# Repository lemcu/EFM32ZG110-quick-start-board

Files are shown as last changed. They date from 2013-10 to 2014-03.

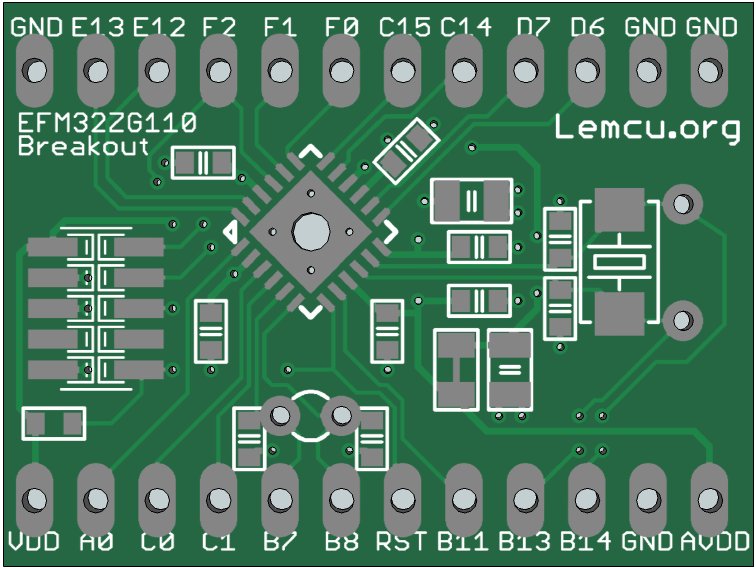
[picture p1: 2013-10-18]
ZeroGecko110BreakoutV1_Top.jpg

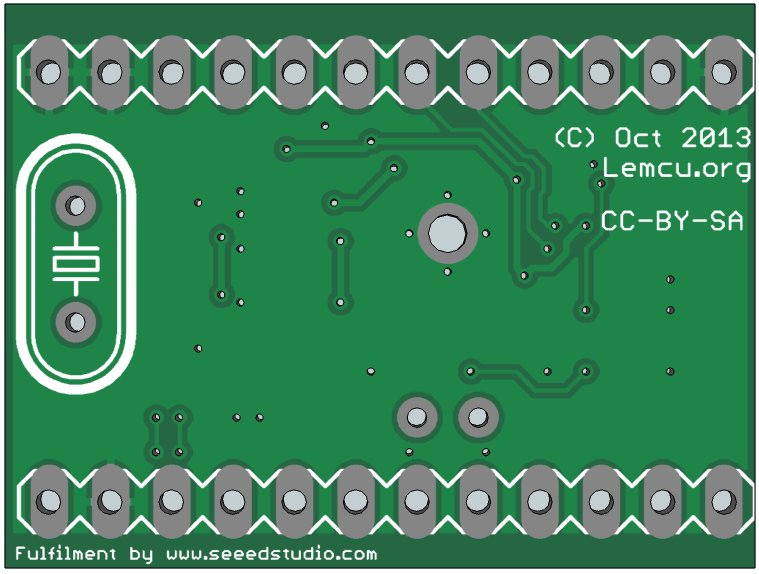
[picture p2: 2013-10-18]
ZeroGecko110BreakoutV1_Bot.jpg

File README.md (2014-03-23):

EFM32ZG110-quick-start-board
============================
This board is designed to be used with [LemcUSB](https://github.com/lemcu/LemcUSB), a purely software based USB peripheral for ARM Cortex M0+ devices.



Zero Gecko 110 quick start breakout board features:

1. USB support using [LemcUSB](https://github.com/lemcu/LemcUSB)
2. 31mm X 23.3mm sized board.
3. Can use either through-hole or SMD High Frequency crystal.
4. Footprint to mount an optional inductor between AVDD and VDD for Analog intensive application.
5. On board SWD Connector.
6. Onboard low noise 3.3V LDO.
7. ESD protection diodes on USB D+ D- lines.

EFM32ZG110 is chosen for presence of onchip ADC instead of EFM32ZG108.




<br />This work is licensed under a <a rel="license" href="http://creativecommons.org/licenses/by-sa/3.0/deed.en_US">Creative Commons Attribution-ShareAlike 3.0 Unported License</a>.

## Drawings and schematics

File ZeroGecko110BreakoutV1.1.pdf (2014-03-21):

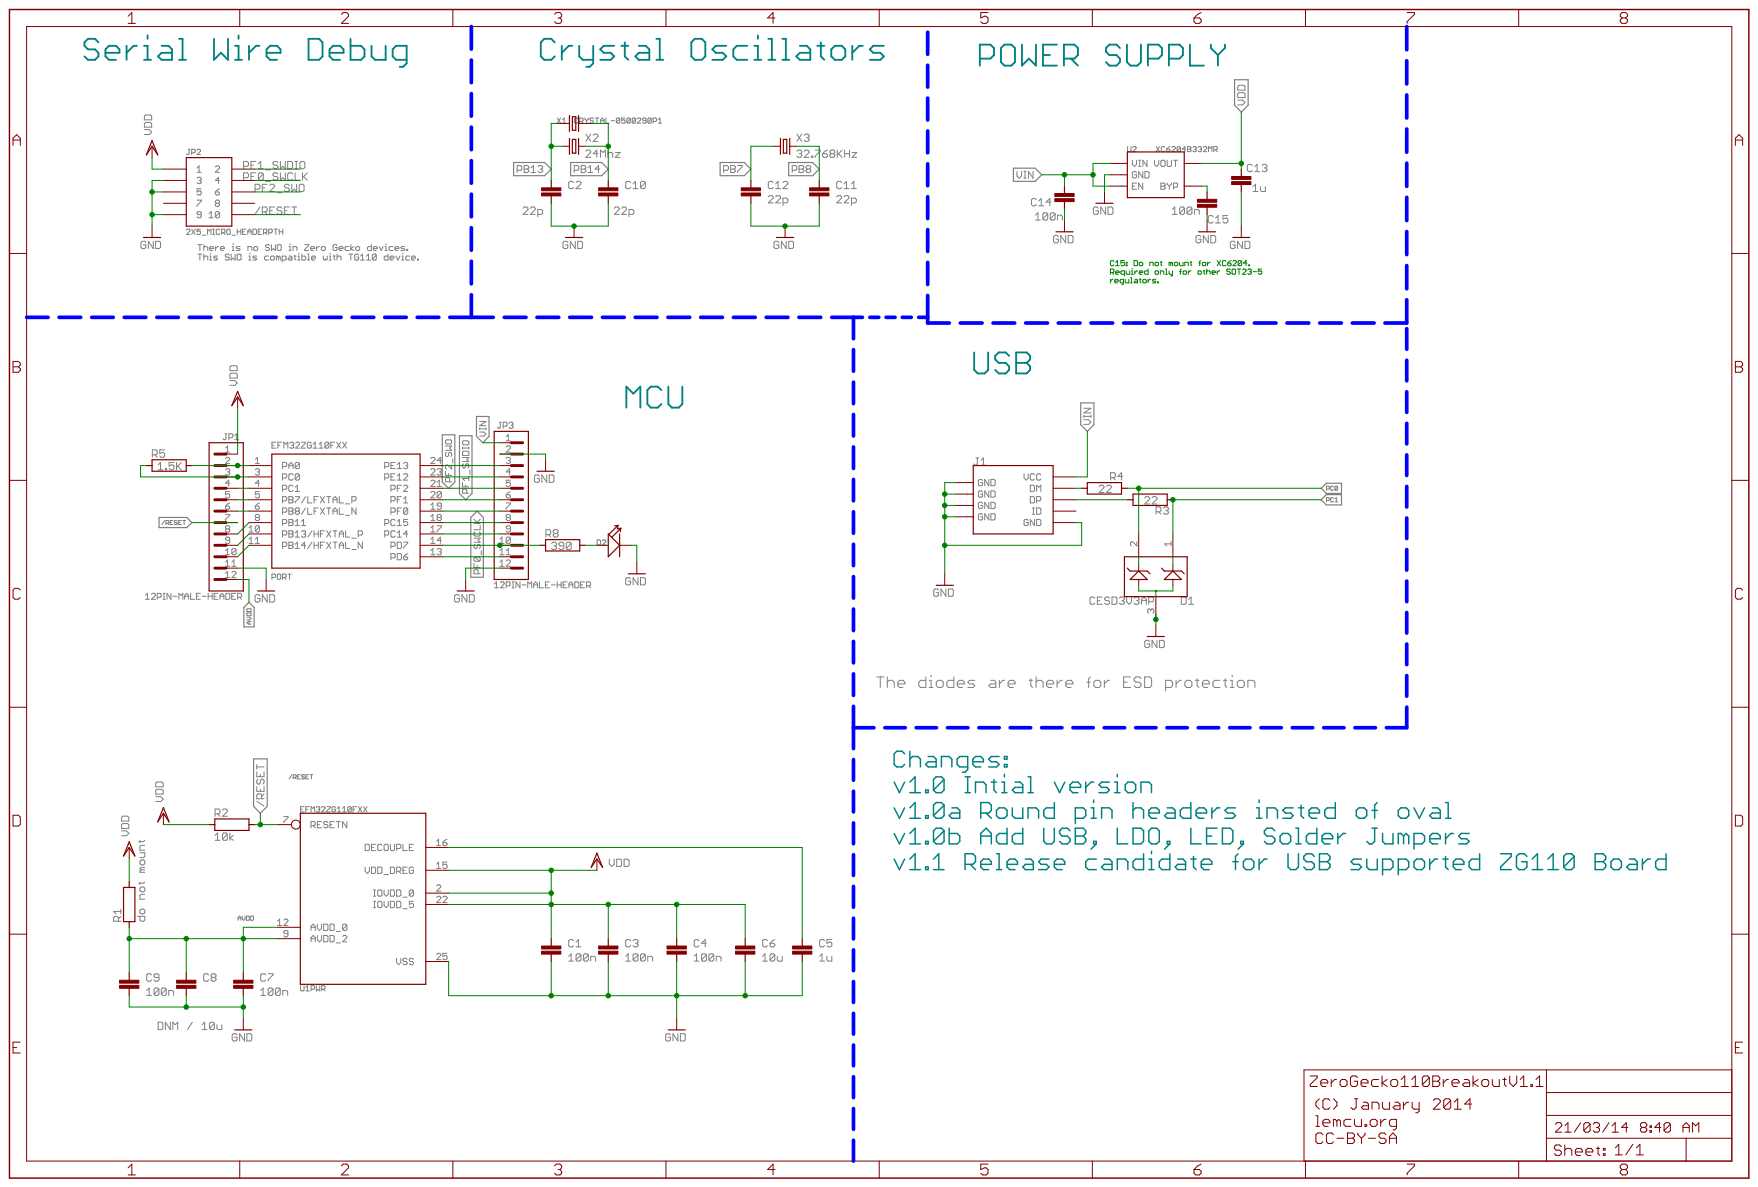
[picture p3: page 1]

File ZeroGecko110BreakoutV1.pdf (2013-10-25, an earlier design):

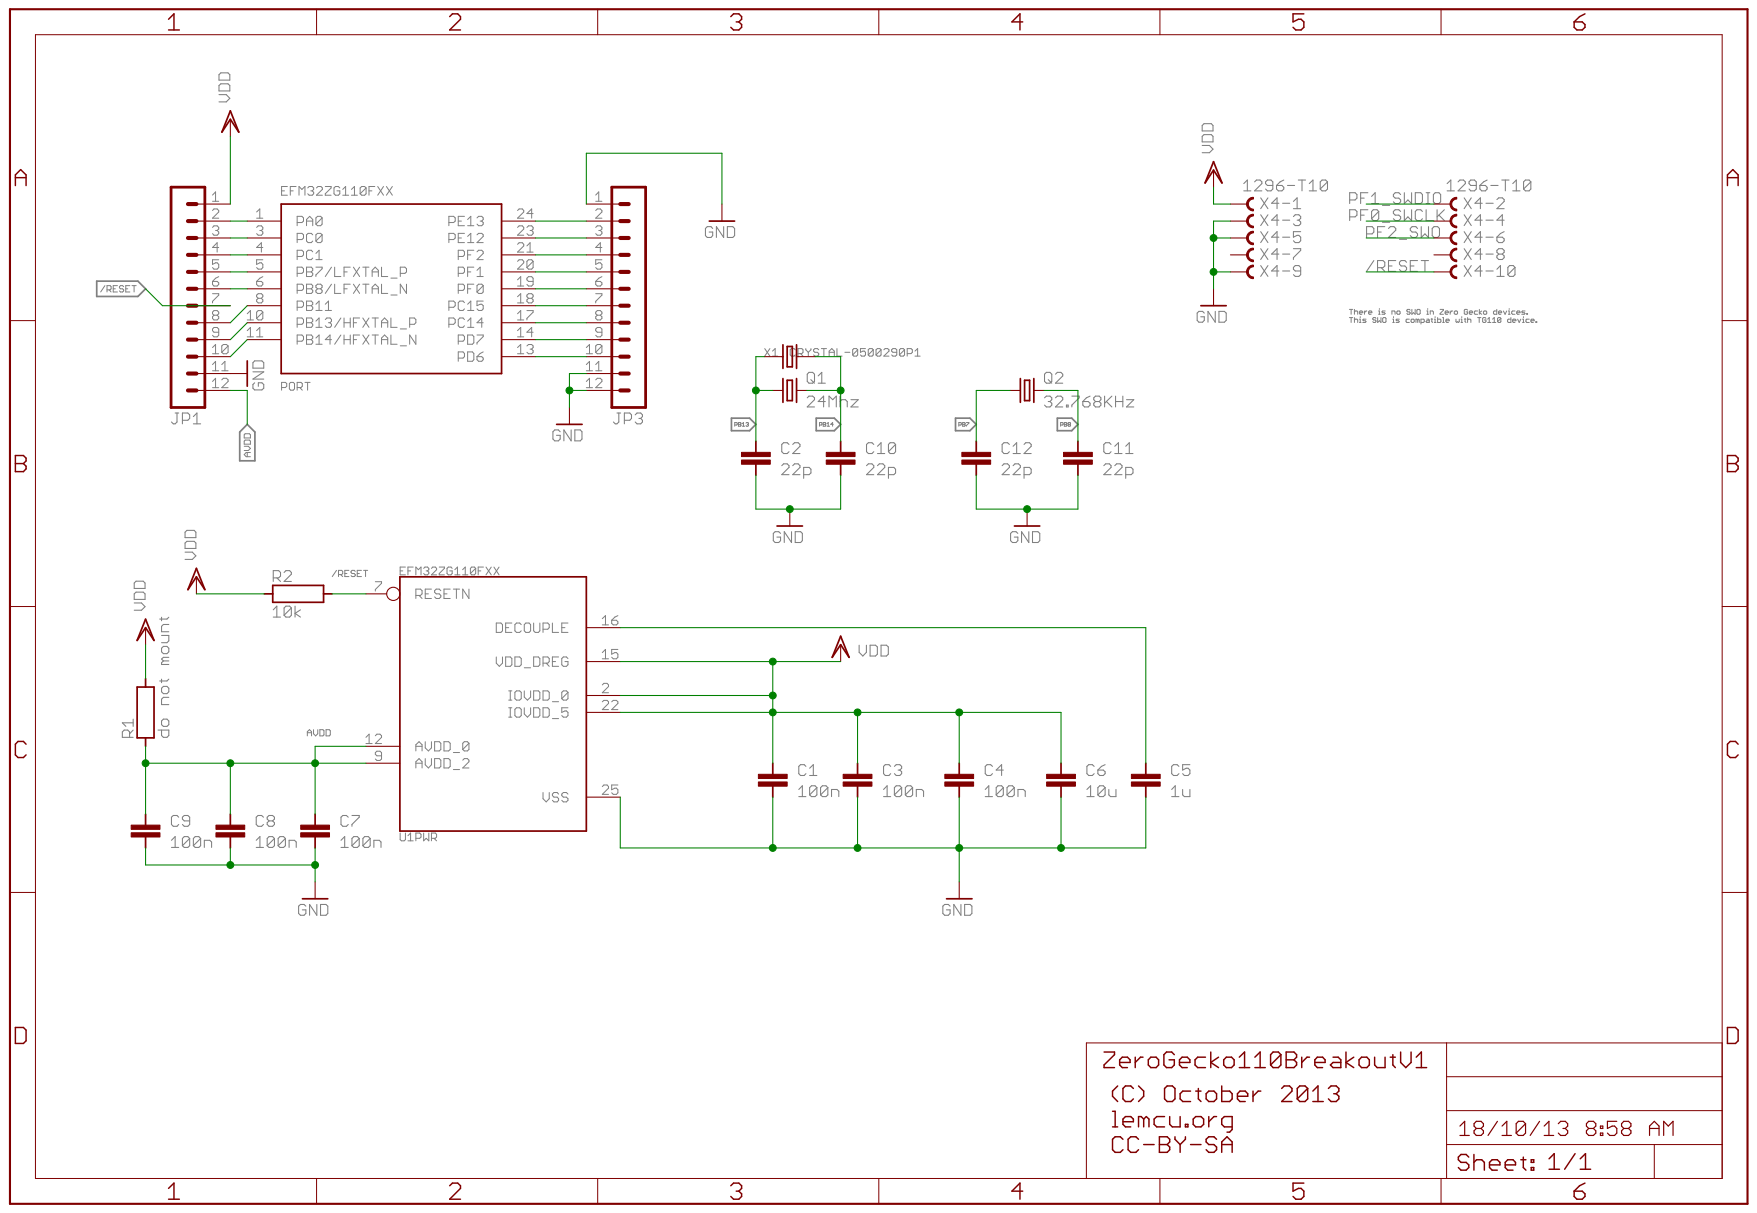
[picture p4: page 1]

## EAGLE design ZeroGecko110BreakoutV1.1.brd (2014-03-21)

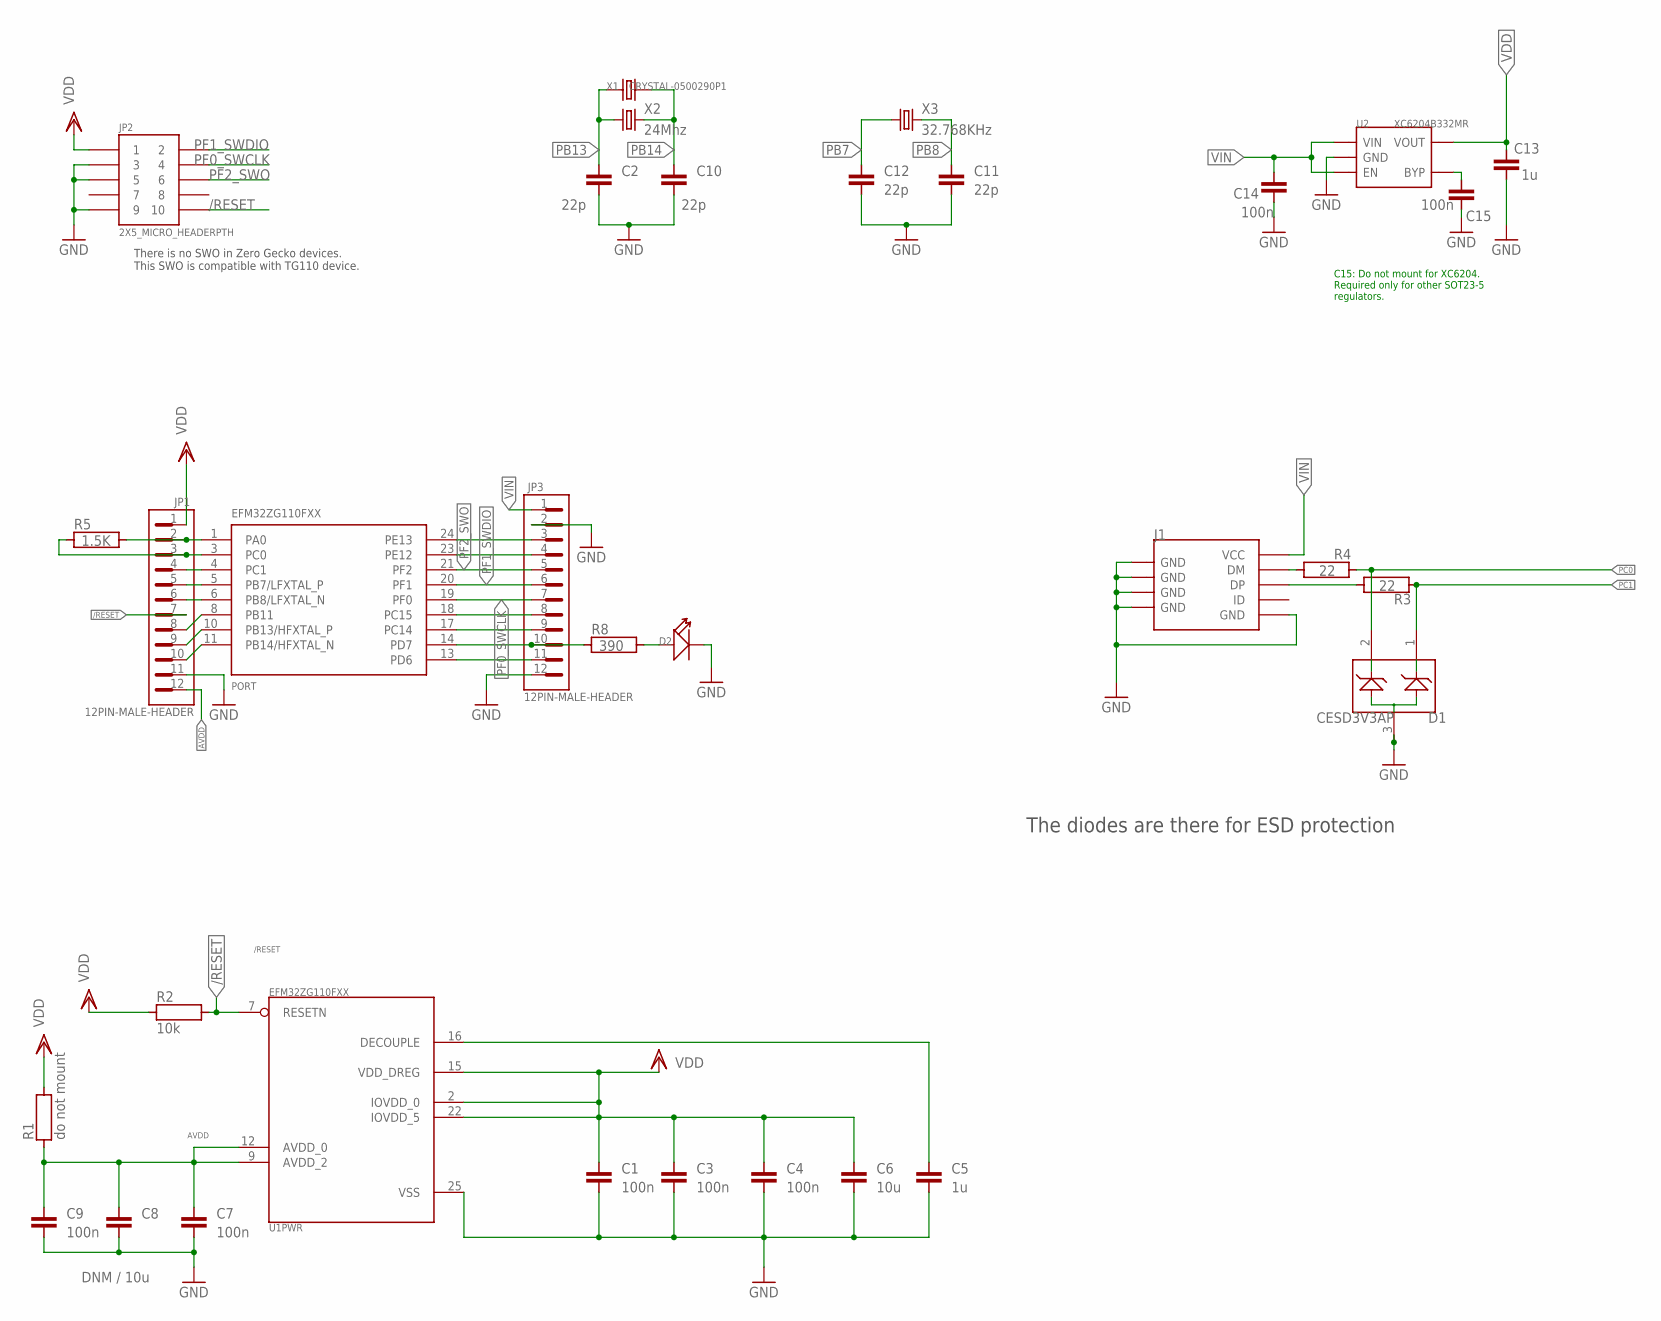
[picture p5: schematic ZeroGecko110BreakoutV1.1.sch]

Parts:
C1, C3, C4, C7, C9: 100n; C0603
C2, C10, C11, C12: 22p; C0603
C5, C13: 1u; C0805
C6: 10u; C0805
C8: DNM / 10u; C0805
C14, C15: 100n; C0805
D1: CESD3V3AP; SOT23
D2: LED; LED0603
J1: USB-MINIUSB-5P-MICRO; MICRO-USB
JP1, JP3: 12PIN-MALE-HEADER; 12P-2.54MM
JP2: 2X5_MICRO_HEADERPTH; 2X5_1.27MM_PTH
R1: do not mount; R0805
R2: 10k; R0603
R3, R4: 22; R0603
R5: 1.5K; R0603
R8: 390; R0603
U1: EFM32ZG110FXX; QFN24
U2: XC6204B332MR; SOT23-5
X1: CRYSTAL-0500290P1; 2P-SMD-5.0X3.2
X2: 24Mhz; HC49U-V
X3: 32.768KHz; TC26V

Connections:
/RESET: JP1.7, JP2.10, R2.2, U1.7 (RESETN)
AVDD: C7.2, C8.2, C9.2, JP1.12, R1.1, U1.9 (AVDD_2), U1.12 (AVDD_0)
GND: C1.1, C2.1, C3.1, C4.1, C5.1, C6.1, C7.1, C8.1, C9.1, C10.1, C11.1, C12.1, C13.1, C14.1, C15.1, D1.3, D2.-, J1.5 (GND), J1.S1 (GND), J1.S2 (GND), J1.S3 (GND), J1.S4 (GND), J1.S5 (GND), J1.S6 (GND), JP1.11, JP2.3, JP2.5, JP2.9, JP3.2, JP3.12, U1.25 (VSS), U2.2 (GND)
unnamed: J1.2 (DM), R4.1
unnamed: J1.3 (DP), R3.1
unnamed: D2.+, R8.2
unnamed: C15.2, U2.4 (BYP)
unnamed: C5.2, U1.16 (DECOUPLE)
PA0: JP1.2, R5.2, U1.1 (PA0)
PB7: C12.2, JP1.5, U1.5 (PB7/LFXTAL_P), X3.1
PB8: C11.2, JP1.6, U1.6 (PB8/LFXTAL_N), X3.2
PB11: JP1.8, U1.8 (PB11)
PB13: C2.2, JP1.9, U1.10 (PB13/HFXTAL_P), X1.1, X2.1
PB14: C10.2, JP1.10, U1.11 (PB14/HFXTAL_N), X1.2, X2.2
PC0: D1.2, JP1.3, R4.2, R5.1, U1.3 (PC0)
PC1: D1.1, JP1.4, R3.2, U1.4 (PC1)
PC14: JP3.9, U1.17 (PC14)
PC15: JP3.8, U1.18 (PC15)
PD6: JP3.11, U1.13 (PD6)
PD7: JP3.10, R8.1, U1.14 (PD7)
PE12: JP3.4, U1.23 (PE12)
PE13: JP3.3, U1.24 (PE13)
PF0_SWCLK: JP2.4, JP3.7, U1.19 (PF0)
PF1_SWDIO: JP2.2, JP3.6, U1.20 (PF1)
PF2_SWO: JP2.6, JP3.5, U1.21 (PF2)
VDD: C1.2, C3.2, C4.2, C6.2, C13.2, JP1.1, JP2.1, R1.2, R2.1, U1.2 (IOVDD_0), U1.15 (VDD_DREG), U1.22 (IOVDD_5), U2.5 (VOUT)
VIN: C14.2, J1.1 (VCC), JP3.1, U2.1 (VIN), U2.3 (EN)

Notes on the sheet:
There is no SWO in Zero Gecko devices. This SWO is compatible with TG110 device.
C15: Do not mount for XC6204. Required only for other SOT23-5 regulators.
The diodes are there for ESD protection

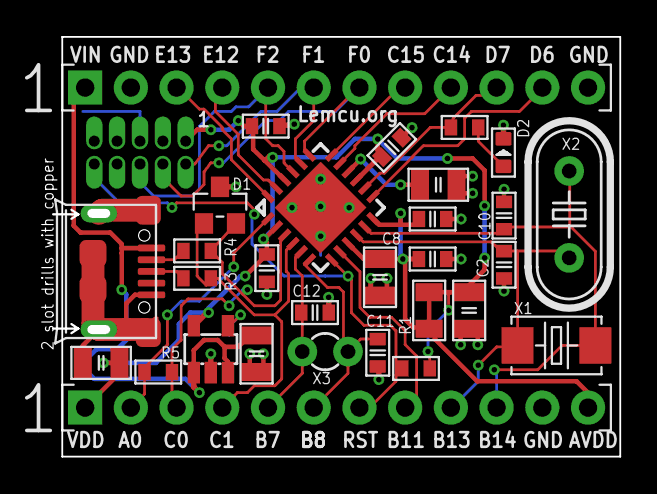
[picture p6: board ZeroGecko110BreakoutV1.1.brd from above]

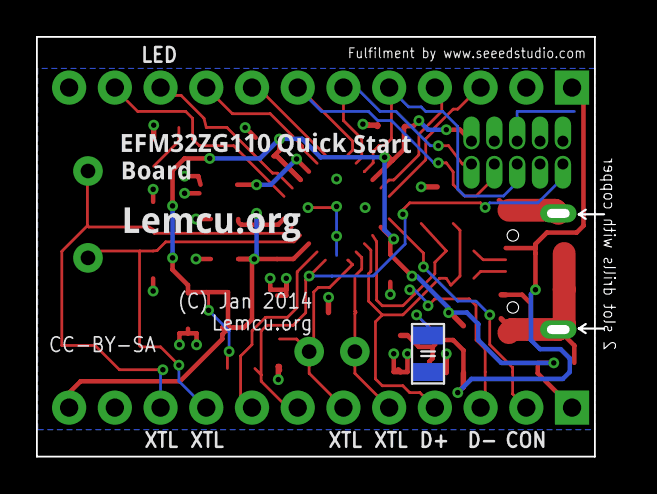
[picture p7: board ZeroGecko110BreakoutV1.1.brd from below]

Board: 2 copper layers, 31.5 x 23.3 mm, 32 parts (2 on the bottom side), 27 nets.

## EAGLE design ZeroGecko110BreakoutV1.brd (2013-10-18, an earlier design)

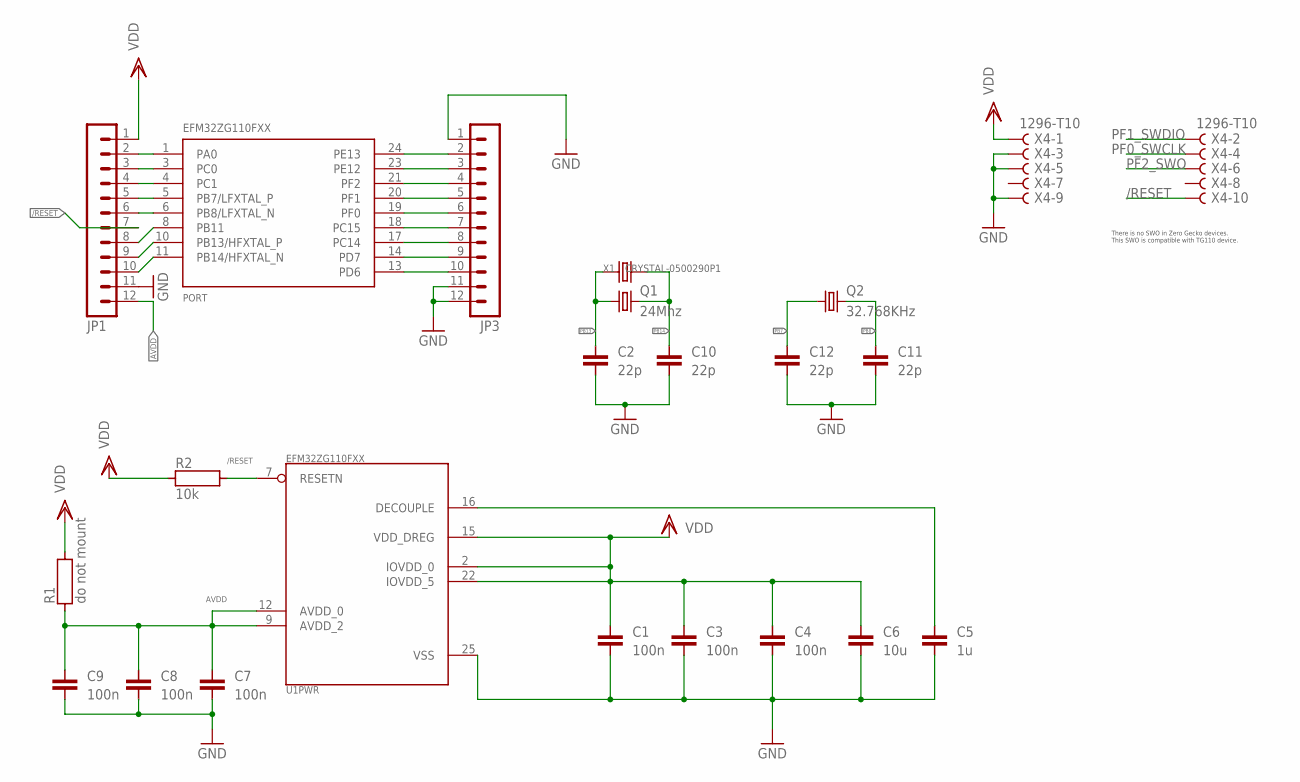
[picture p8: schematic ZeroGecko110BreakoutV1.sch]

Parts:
C1, C3, C4, C7, C8, C9: 100n; C0603
C2, C10, C11, C12: 22p; C0603
C5: 1u; C0805
C6: 10u; C0805
JP1, JP3: MA12-1
Q1: 24Mhz; HC49U-V
Q2: 32.768KHz; TC26V
R1: do not mount; R0805
R2: 10k; R0603
U1: EFM32ZG110FXX; QFN24
X1: CRYSTAL-0500290P1; 2P-SMD-5.0X3.2
X4: 1296-T10; 1296-10

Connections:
/RESET: JP1.7, R2.2, U1.7 (RESETN), X4.10
AVDD: C7.2, C8.2, C9.2, JP1.12, R1.1, U1.9 (AVDD_2), U1.12 (AVDD_0)
GND: C1.1, C2.1, C3.1, C4.1, C5.1, C6.1, C7.1, C8.1, C9.1, C10.1, C11.1, C12.1, JP1.11, JP3.1, JP3.11, JP3.12, U1.25 (VSS), X4.3, X4.5, X4.9
unnamed: C5.2, U1.16 (DECOUPLE)
PA0: JP1.2, U1.1 (PA0)
PB7: C12.2, JP1.5, Q2.1, U1.5 (PB7/LFXTAL_P)
PB8: C11.2, JP1.6, Q2.2, U1.6 (PB8/LFXTAL_N)
PB11: JP1.8, U1.8 (PB11)
PB13: C2.2, JP1.9, Q1.1, U1.10 (PB13/HFXTAL_P), X1.1
PB14: C10.2, JP1.10, Q1.2, U1.11 (PB14/HFXTAL_N), X1.2
PC0: JP1.3, U1.3 (PC0)
PC1: JP1.4, U1.4 (PC1)
PC14: JP3.8, U1.17 (PC14)
PC15: JP3.7, U1.18 (PC15)
PD6: JP3.10, U1.13 (PD6)
PD7: JP3.9, U1.14 (PD7)
PE12: JP3.3, U1.23 (PE12)
PE13: JP3.2, U1.24 (PE13)
PF0_SWCLK: JP3.6, U1.19 (PF0), X4.4
PF1_SWDIO: JP3.5, U1.20 (PF1), X4.2
PF2_SWO: JP3.4, U1.21 (PF2), X4.6
VDD: C1.2, C3.2, C4.2, C6.2, JP1.1, R1.2, R2.1, U1.2 (IOVDD_0), U1.15 (VDD_DREG), U1.22 (IOVDD_5), X4.1

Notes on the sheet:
There is no SWO in Zero Gecko devices. This SWO is compatible with TG110 device.

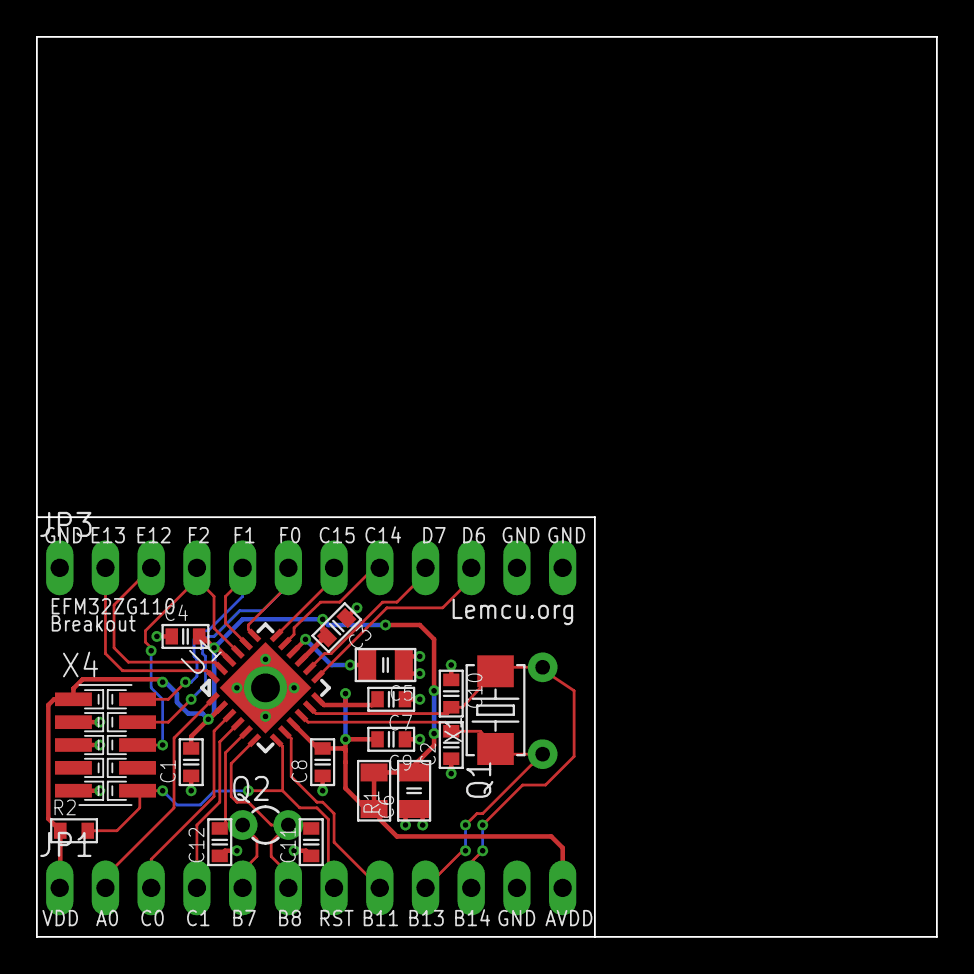
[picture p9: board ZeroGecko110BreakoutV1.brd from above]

Board: 2 copper layers, 50.0 x 50.0 mm, 21 parts (0 on the bottom side), 22 nets.

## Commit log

2013-10-18 Schematic and Board files added
    [ZeroGecko110BreakoutV1.brd, ZeroGecko110BreakoutV1.sch]
2013-10-18 Board screenshot added
2013-10-25 Schematic in PDF added
2014-03-21 v1.1 Release: USB support through LemcUSB firmware-only USB driver
    [ZeroGecko110BreakoutV1.1.brd, ZeroGecko110BreakoutV1.1.sch]
2014-03-23 Update README.md
    Add rendered images for v1.1 PCB

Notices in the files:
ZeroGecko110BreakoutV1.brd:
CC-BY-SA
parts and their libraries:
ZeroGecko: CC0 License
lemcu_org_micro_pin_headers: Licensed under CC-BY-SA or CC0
